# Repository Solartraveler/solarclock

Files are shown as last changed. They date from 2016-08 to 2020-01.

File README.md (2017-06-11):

# solarclock

The aim of this project is to develop an LED alarm clock (DCF77 synchronized),

powered by a solarcell and rechargeable batteries.

A prototype testing for various hardware and a software with most planned
features have been completed.

With Linux, the GUI of the clock can be simulated on PC without building any
hardware. Every menu item can be changed as on the real clock, however there
is no functionality behind the GUI on the PC. Control the simulation with the four
cursor keys.

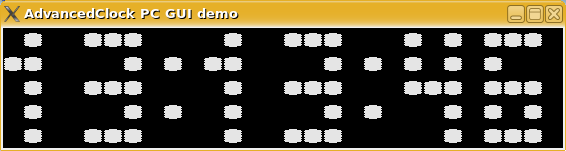
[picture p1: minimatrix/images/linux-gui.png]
Linux GUI simulation


The prototype clock:

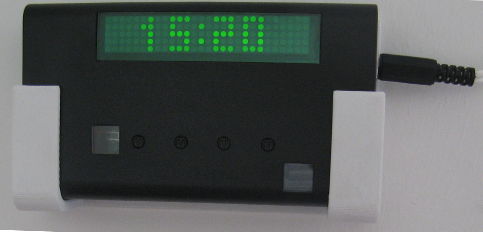
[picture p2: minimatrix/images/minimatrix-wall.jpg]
Real clock


If connected to an external RS232 level converter (19200 baud, no parity,
no extra stop bits, no flowcontrol), and enabled RS232 in the debug
menu, the real clock can be controlled with the w-a-s-d keys over the serial port too.

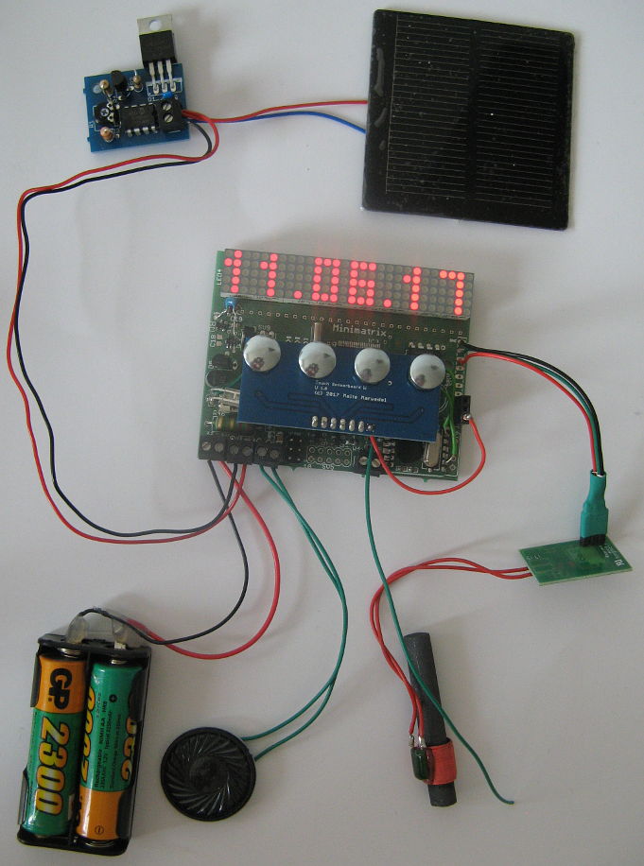
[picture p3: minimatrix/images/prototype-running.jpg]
Version 1.2 without a case


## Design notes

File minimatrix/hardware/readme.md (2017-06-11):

# About the hardware
Version 1.0 is the prototype PCB actually produced.

However it contains a LOT of bugs, so before making your own one, I recommend reading through the bug list and make a new version, starting from the current state of version 1.2.

Please note the new designed ir-sensor board which fits in connector SV2. The ones attached on the v1.0 board simply do not work.

The yellow wires in version 1.1 and 1.2 have been added to the PCB of version 1.0 by wireing on the patchfield.

Genreally, I had two PCBs of version 1.0 produced. The first one is soldered as in schematic version 1.1 and the second one as in schematic 1.2.

Version 1.2 has been improved a bit from version 1.1 and some parts soldered in version 1.1 (but not used there or considered bad) have been removed in version 1.2.

## Userinput

There are two input methods available. Touch and infrared proximity. The software will detect which type is used on startup automatically. Each has its strength and weaknesses. The software could be changed to use classic buttons as third input method with little effort.

## So for the overview of the files:
The brd and sch files are created with Eagle version 5.11 light. The pdf files have been exported from these for easy viewing without the software.

minimatrixV1 brd/sch/pdf: Originally produced PCB, later manually patched to meet the schematics of version 1.1 and 1.2

minimtrixV1-1 brd/sch/pdf: First clock build (the green one). Fixes have been added into the schematic, but not in the board. So you might modify the board before production.

minimtrixV1-2 brd/sch/pdf: Second clock build (the red one). Fixes have been added into the schematic, but not in the board. So you might modify the board before production.

ir-sensorboard brd/sch/pdf: Touchless keys working by infrared reflection sensors. Used on the first clock. Good for use in a kitchen or some other place where you dont want to touch anything. Do not work in bright light, and might get activated by bright flashes by accident. In the daylight they cant be used.

touch-sensorboardW brd/sch/pdf: Use the body capacity as input key. Used on the second clock. Hopefully the ESD protection is sufficient.

solarvoltagelimit brd/sch/pdf: Two schematics and PCBs used for overvoltage and overcurrent protection. The circuit for overcurrent protection is only required for solarcells who can deliver more than 200mA peak. Instead of producing a special PCB, they can be soldered on common perfboard too. Note that the PCBs in these files have never been produced and therefore never tested.

solarclock-touch-voltagelimit brd/pdf: A board from touch-sensorboardW and the voltage limit PCB of solarvoltagelimit combined with predefined breaking points for cheap production as single board.

## License

All my work is published under Attribution-NonCommercial-ShareAlike 4.0 International, however please note that many symbols are work from the authors of the part libraries.

Many symbols are from the Eagle authors.

avr-7.lbr from https://cadsoft.io/resources/libraries/1751/ has been used

And the RFM12 device is from https://www.mikrocontroller.net/topic/90021

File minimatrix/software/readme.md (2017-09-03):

# About the software
The software is divided in two projects. One simple version and one advanced version.

You can edit the menu with my other open source project from

http://menudesigner.sourceforge.net/

## The simple version

Its not containing all planned features of the clock, but is complete enough to run and allow using the clock.
This might be a starting point to get an overview how the code is managed or simply use it if you just dont want a heavily featured clock.
About 29KiB of the flash is used.

### Features:

- DCF77 synchronization

- Showing Date and Time

- Debug print and debug control over RS232

- Adjust brightness according to surrounding brightness

- Charge the batteries

- Set an alarm to a given time -> beep - beep - beep

- Set a counter to give alarm in a given number of minutes.

- Lets the user control with the four keys

- Shows the temperature

- Warns about low battery

- Keylock preventing accidental key presses

- Set RFM12 module to power down mode

- Suppors the infrared (reflex light barrier) keys.

- Many many settings:

  * Brightness manual/automated

  * Show seconds/hide seconds

  * Manual charger control (on/off/automatic)

  * Set mAh of battery

  * Set calibrated value for charge measurement

  * Set level for accepted DCF77 error

  * Set refreshrate

  * Set volume of beep

  * Set frequency of beep

  * Set current consumption for used LEDs

  * Set time until alarm a beeping alarm goes silent without user interaction

  * Select which type debug messages should be printed on the RS232 interface

  * Selects if clock should switch display completely off when dark or stay always at at least minimal brightness

- Showing many informations:

  * Current voltage

  * Current charging current

  * Current charged state of battery

  * Consumend mAh since power on

  * Quality of DCF77 signal

  * Raw value of one key

  * Raw value of lightning sensor

  * Show RC oscillator and CPU usage (percentage of time they are not stopped)

  * And shows even more with RS232 connected

### Known bugs:

- Input keys could be improved, but real bugs - none.

## The advanced version

The advanced version contains all features of the simple version and uses about 50KiB flash.

Unlike the simple clock version, the advanced version contains source code from third parties:

The RC-5 decoder software is from Peter Dannegger.

The two wire interface library is from Atmel Corporation.

The project for the other compatible RFM12 communication endpoint (based on an ATmega8) can be found there: https://www.mikrocontroller.net/topic/71682#4902303

### Completed features

- Event logger in external I2C EEPROM (reboots and cause of it, temperature, chargings, DCF77 sync times and time delta ...)

  * Supports eeproms with one I2C address, two bytes for addressing and at least 16 byte page size.
   This is usually the case for all 8KiB - 64KiB eeproms. Each log entry requires 23 bytes.
   Storing is done FIFO based without explicit index storing, so eeprom life is maximized.
   Size detection is done automatically on first startup.

- RC5 remote control receiver

- Second alarm with repeating, non repeating, only some days of the week, settings

- Power down on certain times of the day, saving power

- Wireless control and read of logger with RFM12

- Manually setting time and date in the case there is no DCF sync

- Test pattern for the LED matrix

- Pin test for checking proper soldering

- Supports both infrared or capacitive keys - does autodetect on startup.

- Calibration of the internal crystal in the range of +- 0.036%

- Heap to stack closest gap (=free RAM) reporting. (77% of the 4KiB are used)

### Planned features

- Its finished :)

### Known bugs:

- Input keys could be improved

- There should be only one clock with an RFM12 active within the RX/TX range - Otherwise both try to act packages from a third station and communication becomes unstable

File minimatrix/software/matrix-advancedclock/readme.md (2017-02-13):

This is the software containing everything you need to have a working alarm clock.
It uses all hardware on the PCB version 1.1 and has many special features therefore "advanced".
Files which are equal to the ones in the simple version are just symlinks. This makes maintaining two versions more easy.

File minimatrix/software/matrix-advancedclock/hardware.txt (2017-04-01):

Hardware:  Interrupt priority:  Prescaler: Modified on speed boost:  Usage:
RTC clock: compare-high         1          no                        used for display
RTC clock: overflow-low         1          no                        used for clock
timer C0:  overflow-low         1          yes                       used for sound                (needs interrupt as long as sound is active)
timer C1:  --                   256        no                        used for performance counter
timer D0:  overflow-medium      1          yes                       used for dcf77 sampling       (needs interrupt as long as signal is syncronizing)
timer D1:  --                   8          yes                       2MHz rc clock synchronization
timer E0:  overflow-low         1          no                        used for RC-5 decoding        (needs interrupt only if incoming signal is detected)
timer E1:  overflow-low         1          yes                       used for RFM12 decoding       (needs interrupt as long as module is active)
USART E0:  tx-medium                       yes                       used for RS232 print           medium level permits debug print in low level interrupts
timer F0:  --                   1          no                        used for touch keys

Possible timer prescalers: 1, 8, 64, 256, 1024
For analyzing the DCF signal, the CPU speed is boosted from 2MHz to 16MHz,
this requires a change of the running timers to preventing running faster.
Therefore the prescalers are changed from 1 to 8 and from 8 to 64 for timers
where this matters.

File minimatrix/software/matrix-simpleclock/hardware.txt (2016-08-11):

RTC clock: Used for display + rtc
timer C0: used for sound
timer C1: used for performance counter
timer D0: used for dcf77 sampling
timer D1: 2MHz rc clock synchronization

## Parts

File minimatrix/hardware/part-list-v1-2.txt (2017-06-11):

This is the part list for schematic version 1.2.
It is build on the patched PCB of version 1.0
PCB1 is the main PCB with the matrix and ATxmega.
PCB2 is the required extra PCB for the voltage limitation of the solar cell.
PCB3 is the touch keys PCB.

Number  Description              Part of:                                   Supplier     Order-number      approx price for 1x in Euro
 1x     24AA512P 32KB EEPROM     IC1                                        Reichelt     24AA512-I/P       1.85
 1x     Opamp MCP6051            IC2                                        Reichelt     MCP 6051T-E/OT    0.69
 1x     ATxmega 100QFP 64KB      IC3                                        Reichelt     ATXMEGA 64A1-AU   4.95
 1x     RFM12                    U$2                                        Pollin       810 049           4.95
 1x     MCP6042P                 PCB2:IC2A                                  Reichelt     MCP 6042-I/P      0.93
 1x     LPT80A Phototransistor   T1                                         Reichelt     LPT 80            0.70
 1x     Temperature Sensor       R1                                         Reichelt     KTY 81-221        0.57
 1x     47k 0805                 R2                                         Reichelt     SMD-0805 47,0K    0.03
 2x     220 0805                 R3, R4                                     Reichelt     SMD-0805 220      0.03
 6x     1000k 0805               R5, R38, PCB3:R13-R16                      Reichelt     SMD-0805 1,00M    0.03
28x     Resistors for LEDs 27Ohm R6-R33                                     Reichelt     SMD-0805 27,0     0.015
 1x     33k 0805                 R34                                        Reichelt     SMD-0805 33,0K    0.03
 1x     Potentionmeter 100k      R35                                        Reichelt     PT 6-S 100K       0.24
 1x     110k 0805                R36                                        Reichelt     SPR-0805 110K     0.24
 3x     220k 0805                R37, R40, R41                              Reichelt     SMD-0805 220K     0.03
 2x     360k 0805                R42, R43                                   Reichelt     RND 0805 1 360K   0.02
 2x     100k 0805                R44, R45                                   Reichelt     SMD-0805 100K     0.03
 1x     2,2Ohm resistor          R46                                        Reichelt     2W METALL 2,2     0.13
 4x     100k 1206                PCB3:R9-R12                                Reichelt     RND 1206 1 100K   0.02
 1x     47k                      Patchfield                                 Reichelt     1/4W 47K          0.103
 1x     1k                       Patchfield                                 Reichelt     1/4W 1,0K         0.103
 1x     Poti 100k                PCB2:R1                                    Reichelt     PT 6-L 100K       0.27
 1x     100k                     PCB2:R2                                    Reichelt     1/4W 100K         0.103
 1x     240k                     PCB2:R3                                    Reichelt     1/4W 240K         0.103
16x     Condensators 100nF 0805  C2, C3, C6-C9, C12-C17, C19, PCB3: C9-C11  Reichelt     X7R-G0805 100N    0.05
 2x     100µF 1206               C20, C21                                   Reichelt     X5R-G1206 100/6   0.34
 1x     47µF 1206                C22                                        Reichelt     X5R-G1206 47/6    0.20
 2x     100nF                    Patch between R35 and R36, PCB2:C1         Reichelt     X7R-2,5 100N      0.05
 4x     1nF 3000V                PCB3:C1-C4                                 Reichelt     X7R 1812 CN 1,0N  0.16
 4x     10nF 200V                PCB3:C5-C8                                 Reichelt     X7R 0805 CH 10N   0.04
 1x     1N5817-B                 D4                                         Reichelt     1N 5817           0.06
 2x     Z-Diode LM385Z-1.2       D5, PCB2:D1                                Reichelt     LM 385-Z1,2       0.39
 8x     SM6T36A                  PCB3:D1-D8                                 Reichelt     P6SMB 36A SMD     0.17
 4x     7x5 red   TA07-11SURKWA  LED1-LED4                                  RS           719-2572          2.31
 8x     IRLML6402PbF P-Mosfet    Q3-Q10                                     Reichelt     IRLML 6402        0.15
 2x     BSS138       N-Mosfet    Q11, Q12                                   Reichelt     BSS 138 SMD       0.04
 1x     IRLZ34N                  PCB2:Q1                                    Reichelt     IRLZ 34N          0.45
 1x     Oscillator 32kHz         Q2                                         Reichelt     0,032768          0.12
 1x     Fuse with Socket 250mA   U$3                                        Reichelt     SMD-HASF 0,25A    1.10
 1x     Pin header 2x3           SV1                                        Reichelt     MPE 087-2-006     0.14
 1x     Plug connector 6pin      SV2                                        Reichelt     MPE 094-1-006     0.21
 2x     Plug connector 3pin      SV4, and with wire on SV4                  Reichelt     MPE 094-1-003     0.13
 1x     Pin header 1x6           split: PCB3: SV1, with wire on PCB3:Pad1   Reichelt     MPE 087-1-007     0.16
 5x     Screwed connection       J1 - J4, PCB2:J1                           Reichelt     AKL 059-02        0.24
 1x     NIMH AA 2er pack                                                    Reichelt     ENELOOP 2XAA      5.40
 1x     Battery holder           connect to J2                              Reichelt     HALTER 2XAAZ      0.35
 1x     Speaker                  connect to J3                              Reichelt     BL 28             1.50
 1x     DCF77 receiver           connect to SV4                             ELV          68-09 16 10       9.95
 1x     Solarcell 200mA-250mA 4V connect to J1                              Ebay                          ~9.00
 1x     PCB production           PCB1                                       Platinensammler.de            31.72
 1x     PCB production           PCB2, PCB3                                 electrow.com                 ~10.00
                                                                                                   Sum: ~103.78€
 1x     Some wire/strand for Solar cell, batteries, speaker and DCF77 connector
 1x     Some case
 1x     Some glass or acrylic glass for the solar cell
 1x     Some transparent-red acrylic glass for the display
 4x     Small metal plates as touch buttons (for example use 4mm screws)
 1x     Some PB-free tin-solder
 1x     Some heat shrink tube
 1x     Some hot glue
 6x     Shipping for Reichelt, Pollin, RS, ELV, Platinensammler or electrow.com, acrylic glass           ~5.00

Possible changes in options from the list above:
A: Remove RFM12
   U$2 and C3 100nF not needed
B: Remove Logger
   IC1 and C6 100nF not needed
C: Remove Beeper
   C22, Q10, Q12, R41, J1, Speaker not needed
D: Reduce batteries from AA to AAA and select other battery holder.
   Make sure allowed charging current is higher or equal the maximum current of the solar cell.
E: Increase or decrease solar cell. If increasing to > 250mA, add a current limiting polyfuse.
   to make sure the batteries are not fast overcharged in the case of software/hardware failure.
F: Instead of the red matrix LEDs (LED1-LED4), orange or green parts can be used:
   orange: TA07-11SEKWA
   green:  TA07-11CGKWA
G: An IR receiver can be added:
   Add 1x 100nF 0805 (C1) and 1x TSOP 31238 (IR1)
H: The wires can be directly soldered to the PCB, remove all "Screwed connection" J1-J4, PCB2:J1
I: Instead of the touch buttons, the IR buttons (ir-sensorboard PCB) can be used:
   Remove all parts for PCB3, Add PCB4.
   Add 1x IRML6402, 4x 39 0805, 4x 47k 0805, 4x SG2BC
J: The LEDs and the EEprom can be placed in a socket (testing different colors etc)
   Add 4x Socket DIL 14, 1x Socket DIL 8
   Placing the LEDs into a socket is recommend as it helps equaling the height of them to the touch buttons.

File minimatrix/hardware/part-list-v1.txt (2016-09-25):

BE CAREFUL, this list is for parts of PCB vesion 1.0. Some parts not have been replaced on version 1.1 (old parts are on this list, new ones not).

Bauteilhöhe Poti: 7,7mm
LED + Sockel Höhe: Sockel=4,1mm  LED= 6,4mm -> 10,5

PCB Dimension:
75x60x(10,5+1.5+3)=75x60x15
Akku Dimension: 58x32x(13,5+2mm) = 15,5mm
-> Höhe = 31mm

Optionen: Jeweils entweder A, B oder C bestellen

Selber gewählt: 1A, 2B, 3B, 4A, 5B

Bauteile                  Reichelt Bestellnummer   €
1x ATxmega 100QFP 64KB    ATXMEGA 64A1-AU   4,95 Option 4A
1x ATxmega 100QFP 128KB   ATXMEGA 128A1-AU  6,60 Option 4B
1x IR 38KHz TSOP31238     TSOP 31238        0,77 Option 3A
1x IR 36kHz TSOP31236     TSOP 31236        0,77 Option 3B
1x 24FC64P  8KB EEROM     24FC64-I/P        0,54 Option 5A
1x 24AA256P 32KB EEPROM   24AA256-I/P       1,05 Option 5B
1x 24AA1025 128KB EEPROM  24AA1025-I/P      3,50 Option 5C (software only supports up to 64KB right now)
1x LHI878 PIR Sensor      LHI 878 RF        2,70
1x LPT80A Fototransistor  LPT 80            0,70
1x Temp Sensor 2k         KTY 81-221        0,57
1x Poti 100k CA6H         PT 6-S 100K       0,24
1x MCP6051                MCP 6051T-E/OT    0,69
1x LM385Z-1.2             LM 385-Z1,2       0,39  Option 1A
1x LT1004C-1.2            LT 1004 CZ-1,2    1,95  Option 1B (spart 15µA)
15x 100nF 0805            X7R-G0805 100N    0,05
8x IRLML6402PbF           IRLML 6402        0,15
                                          ZwSumme=14,01
2x BSS138                 BSS 138 SMD       0,04
3x 100µF 1206             X5R-G1206 100/6   0,34 Option 6A (ausverkauft)
3x 47µF 1206              X5R-G1206 47/6    0,20 Optoin 6B
12x 22pF 0805             NPO-G0805 22P     0,05
1x 1 15mm                 2W METALL 1,0     0,11
20x 27 0805               SMD-0805 27,0     0,082
2x 220 0805               SMD-0805 220      0,103
2x 4.7k 0805              SMD-0805 4,70K    0,103
1x 47k 0805               SMD-0805 47,0K    0,103
1x 68k 0805               SMD-0805 68,0K    0,103 Option 1A
1x 33k 0805               SMD-0805 33,0K    0,103 Option 1B
2x 100k 0805              SMD-0805 100K     0,103
                                          ZwSumme=4,411
1x 110k 0805              SPR-0805 110K     0,24
1x 200k 0805              SPR-0805 220K     0,24
3x 220k 0805              SMD-0805 220K     0,103
1x 1000k 0805             SMD-0805 1,00M    0,103
24x 10000k 0805           SMD-0805 10,0M    0,082
1x Spule 10µH             L-MICC 10µ        0,15
1x 1N5817-B               1N 5817           0,06
1x Quarz 32kHz            0,032768          0,12
1x Quarz 4MHz             4,0000-HC49U-S    0,19
1x Sicherung 250mA        SMD-HASF 0,25A    1,10
1x Stiftleiste 2x5        MPE 087-2-010     0,25
1x Stiftleiste 1x3        MPE 087-1-003     0,08 Option 2A
                                          ZwSumme=4,81
1x Stiftleiste 2x3        MPE 087-2-008     0,20
2x Stiftleiste 1x2        MPE 087-1-002     0,05 Option 2A
2x Stiftleiste 1x6        MPE 087-1-006     0,15 Option 2A
1x Stiftleiste 1x40       SL 1X40G 2,54     0,18 Option 2B

1x Buchsenleiste 1x10     BL 1X10G8 2,54    0,18
1x Buchsenleiste 1x6      MPE 094-1-006     0,25
4x Schraubanschluss 1x2   AKL 059-02        0,24
4x Sockel DIL 14          GS 14             0,04
1x Sockel DIL 8           GS 8              0,04
1x Fresnel Linse          FRESNEL-0650      1,80
2x Akkus NIMH AA          ENELOOP 4XAA      10,50 /[4Stück]
1x Akkuhalter             HALTER 2XAAZ      0,35
1x Lautsprecher           BL 28             1,50
                                          ZwSumme=11,09
1x Gehäuse
1x Solarzelle 3V          -------  ca 3,3V Leerlauf , 360mA max.      ~20,00
1x PCB Herstellung        -------  mikrocontroller.net Platinensammler 31,72
1x RFM12                  -------  Pollin    810 049                    4,95
4x LED Matrix Module      -------  RS        TA07-11CGKWA               2,77

Total: 93,76

IR Sensor board:
1x IRML6402                                            Q1
4x 39 0805                                  0,103      R1, R2, R3, R4
4x 47k 0805                                 0,103      R5, R6, R7, R8

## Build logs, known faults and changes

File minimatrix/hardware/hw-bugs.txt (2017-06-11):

Version 1.0 of the board contains the following bugs:
The changes are documented in version 1.1 and 1.2, however no such new PCB has been produced.

1. TWI
   Problem: TWI misses the ~2k pull up resistors on both signals.
   Workaround: Use TWI with internal 20k pull-up resistors. This will only work on very low clock frequencies.
2. Light sensor
   To measure the full dynamic of the surrounding, different values for R2 are needed.
   Workaround: Use R2 = 1MOhm, and connect PE4 with 100kOhm and PE7 with 4.7kOhm to the photo transistor.
   Note: Due connection of R2 with R5, measurements with PE4 or PE7 as high, must remove the effects of T1 by measuring T1 and do some math.
3. JTAG
   The connector is too close to J4.
   Workaround: Use PDI for programming or do not equip J4.
   Note: JTAG has never been tested.
4. Jumpers J1, J2, J3, J4
   4.1 The jumpers are lager than expected. Text in front can't be read. Workaround: None
   4.2 D4 has too less space. Workaround: Solder D4 from the bottom
5. LED Voltage regulator
   5.1 Disconnecting the power supply by opening SV9, results in VCC as VCCLED. TOO HIGH VOLTAGE! Workaround: Never open SV9 unless all matrix LEDs are off. Only open tesing purpose (eg measuring current consumptions).
   5.2 C18 makes regulation bad. Workaround: Don't equip C18.
   5.3 Regulation swings. Workaround: Connect 100nF from VCCLED to the positive input of IC2.
   5.4 Regulation swings. C20 is too small. Use at least 150µF. Connect an additional electrolyte in parallel.
   5.5 The planned 30Ohm as resistor for the LEDs cant be bought easily. Workaround: Use 27Ohm.
6. Touch
   Do not equip C23 ... C30.
   Sensitivity too low. Make PCB sensing field larger. Or better use IR distance sensors (other .brd file)
7. Level converter for PDI bad.
   Workaround: Do not equip SV8, D1, D2. Lower R3, R4 to 200Ohm. Use 3.3V programmer.
8. Too high power consumption
   Do not equip D3.
9. Screw holes
   The screw holes are too close to some pads.
   Workaround: Do not use or use isolated screws.
10. Crystals
   10.1 There are vias below Q1 ans Q2 which may result in a short circuit if the crystal touches these.
        Workaround: Solder pins of Q1 with some distance to the PCB. Add some isolating tape below Q2.
   10.2 C10 and C11 are not needed. Do not equip.
11. SV4
   The holes only allow soldering female header and are too small for male header.
   Workaround: Use female header.
12. RFM12:
  12.1 There are vias below the RFM12 module wich might result in short circuit
   Workaround: Put a piece of paper between pcb and RFM12 while soldering, remove later -> results in some space between PCBs
  12.2 RFM12 needs external reset for proper operation
   Woraround: Connect pin PE5 from PIR detector to reset (do not use PIR detector)
13. PIR Detector does not work
   Workaround: Do not solder PIR detector and R39
14. R42 and R43 are too low, resulting in a maximum voltage measurement range of 3.2V -> not enough for charger
   Workaround: Solder 360kOhm for both resistors
15. Charging current cant be measured very well
  Use 2.2Ohm for R46.

==ir-sensor==
16. The ir-sensor board uses SG2-BC photointerrupters as contact-free keys. However direct sunlight results in accidential key presses and intentional key presses become impossible.
   Workaround: Only use clock in the shadow from the sun or with artifical light.
==touch-sensor==
17. The Diodes D1-D8 in the PCB are difficult to solder when C1-C4 are already soldered.
   Workaround: Solder D1-D8 before soldering C1-C4.
==Voltage limit==
18. The 75k potentiometer is difficult to buy.
   Workaround: Use 100k

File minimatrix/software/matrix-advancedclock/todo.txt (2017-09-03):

Advanced clock TODO:
Display flicker                     -> Done, needs longtime testing. Needs to check if problem is solved even without enabled workaround in debug menu (increases the power consumtion a little)
Power save mode selectable          -> Done
Power save mode for specific times  -> Done
RC-5 Receiver                       -> Done
RFM12 RX/TX                         -> Done
Advanced timer                      -> Done
Pin Selftest                        -> Done
Logger                              -> Done
Reboot/runtime counter              -> Done
Redundant config load/store         -> Done
Crashes on keypress                 -> Done
Touch keys                          -> Done
Smooth brightness adjust            -> Done (source of flicker while brightness reduce is likely caused by insufficient LED voltage regulation)
Summer winter time adjust           -> Done
DCF77 sync wait time adjustable     -> Done
Logger status write time adjustable -> Done
Manual time adjust                  -> Done
Manual charger state adjust         -> Done
Auto powersave on critical voltage  -> Done
Calibration option for crystal      -> Done
Test Patterns                       -> Done
IR Keys                             -> Done

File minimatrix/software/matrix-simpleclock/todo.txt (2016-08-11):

Charger working -> ok
Better DCF77    -> ok
Better Keys     -> ok
Power estimator -> ok
Display flicker -> still no idea

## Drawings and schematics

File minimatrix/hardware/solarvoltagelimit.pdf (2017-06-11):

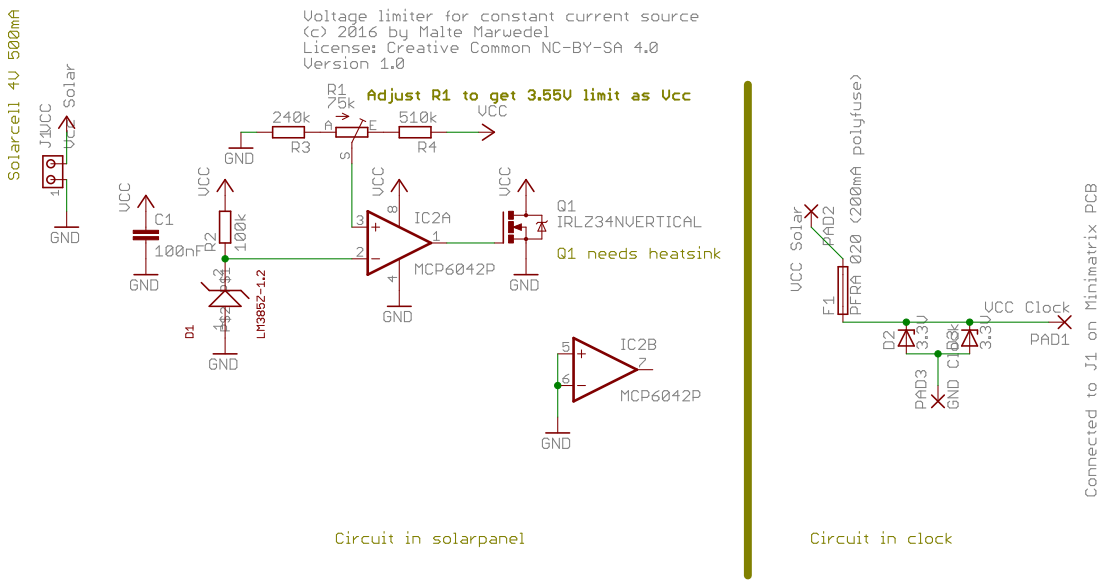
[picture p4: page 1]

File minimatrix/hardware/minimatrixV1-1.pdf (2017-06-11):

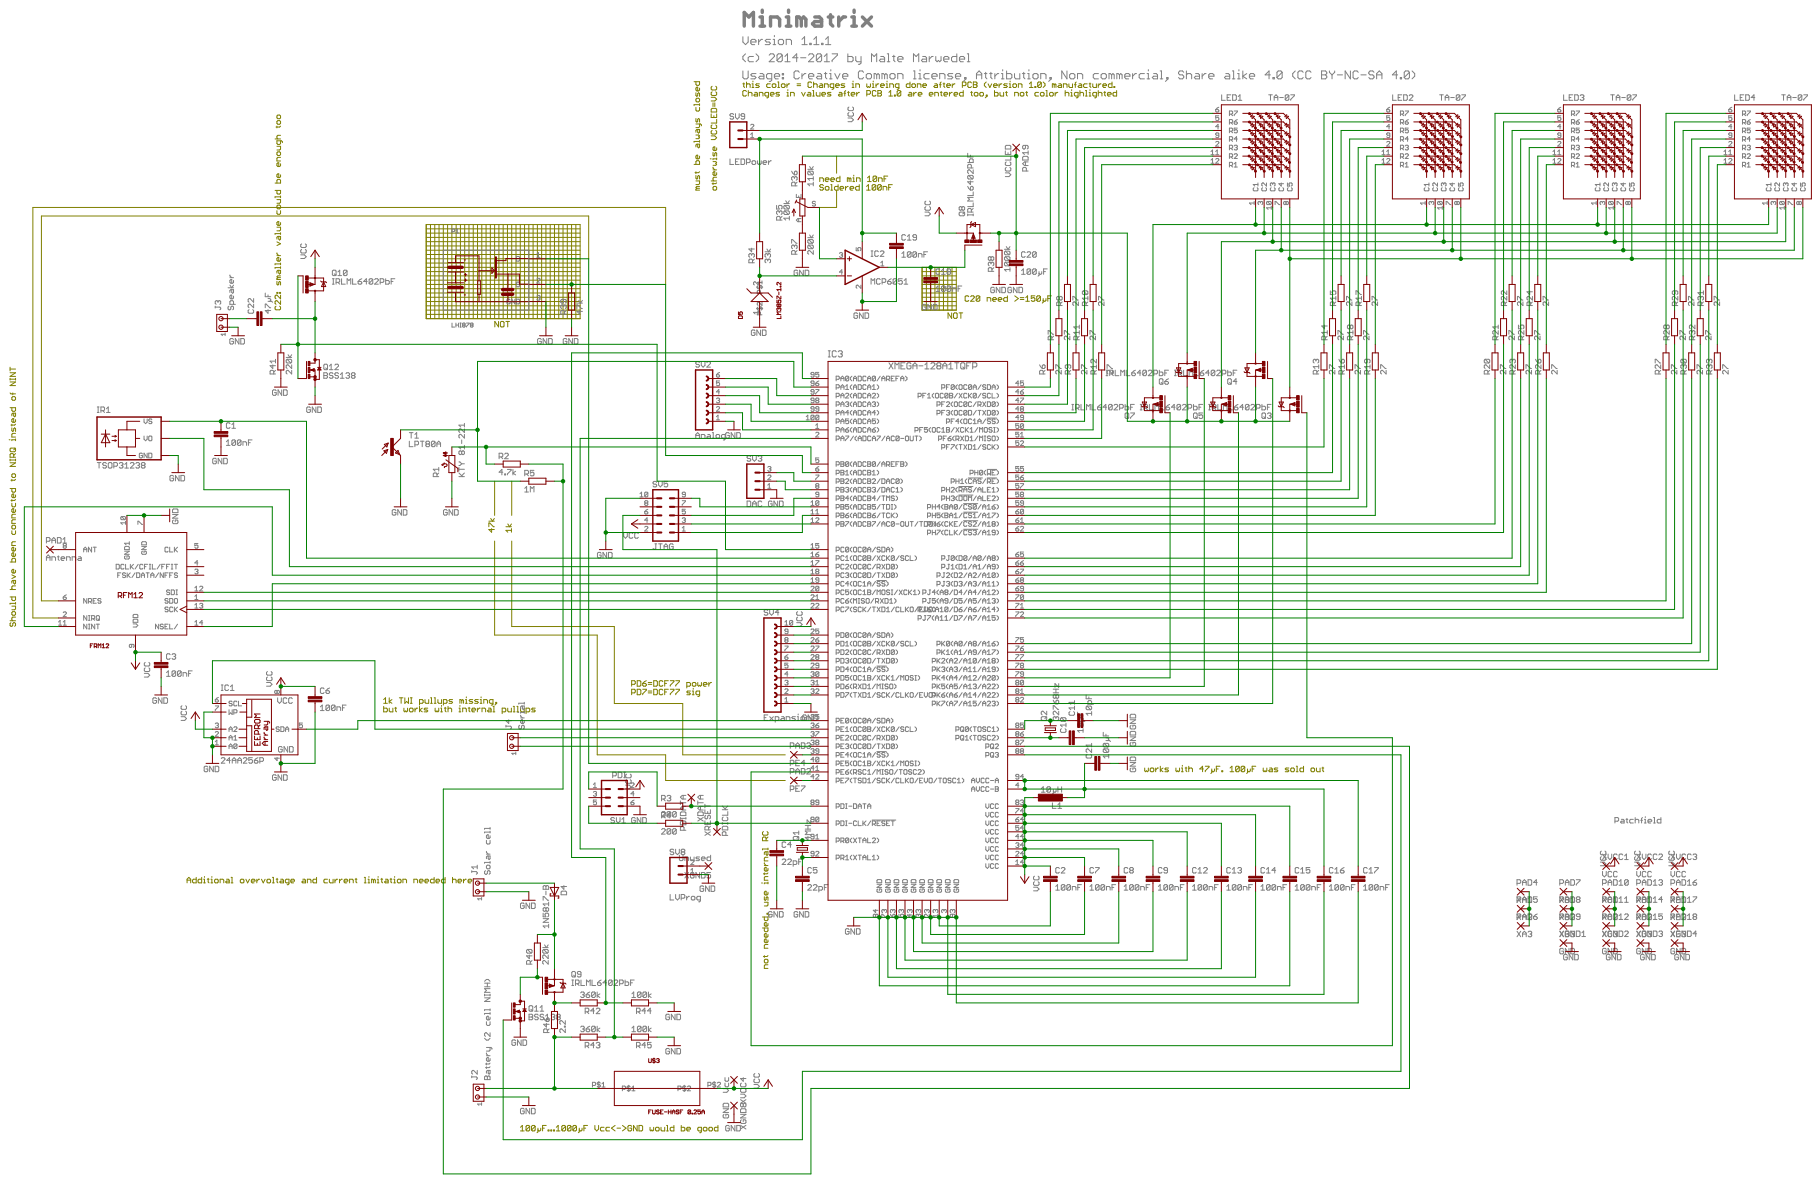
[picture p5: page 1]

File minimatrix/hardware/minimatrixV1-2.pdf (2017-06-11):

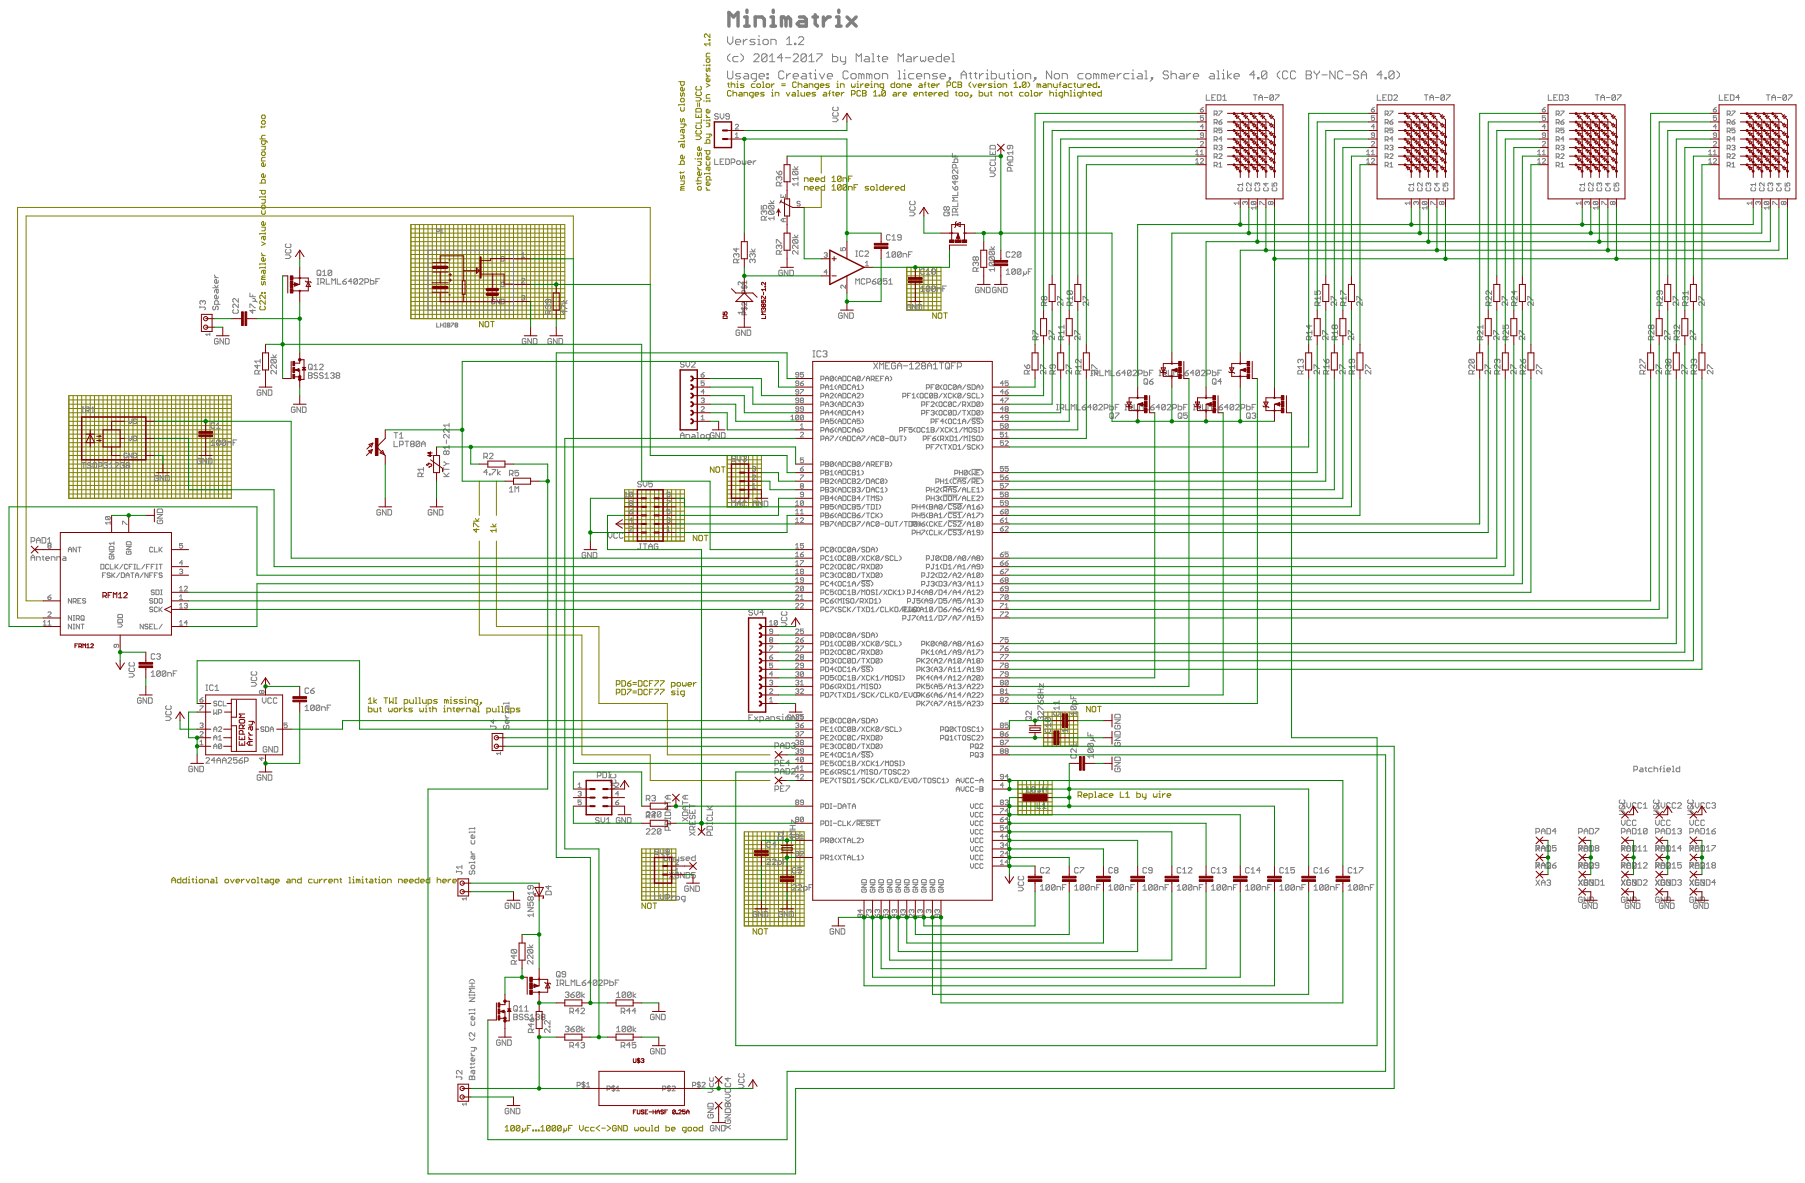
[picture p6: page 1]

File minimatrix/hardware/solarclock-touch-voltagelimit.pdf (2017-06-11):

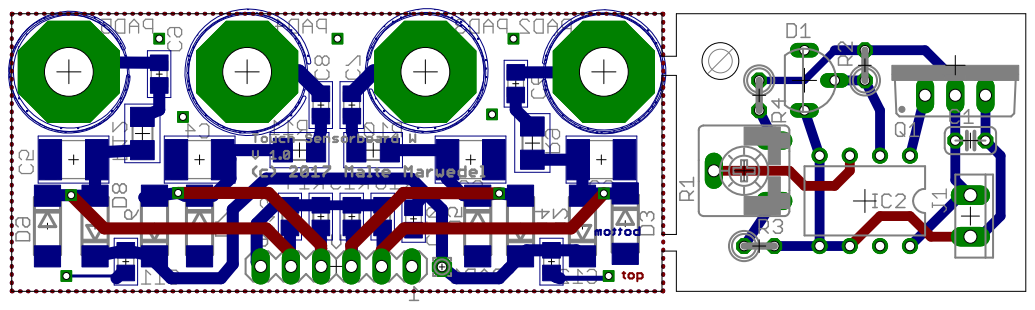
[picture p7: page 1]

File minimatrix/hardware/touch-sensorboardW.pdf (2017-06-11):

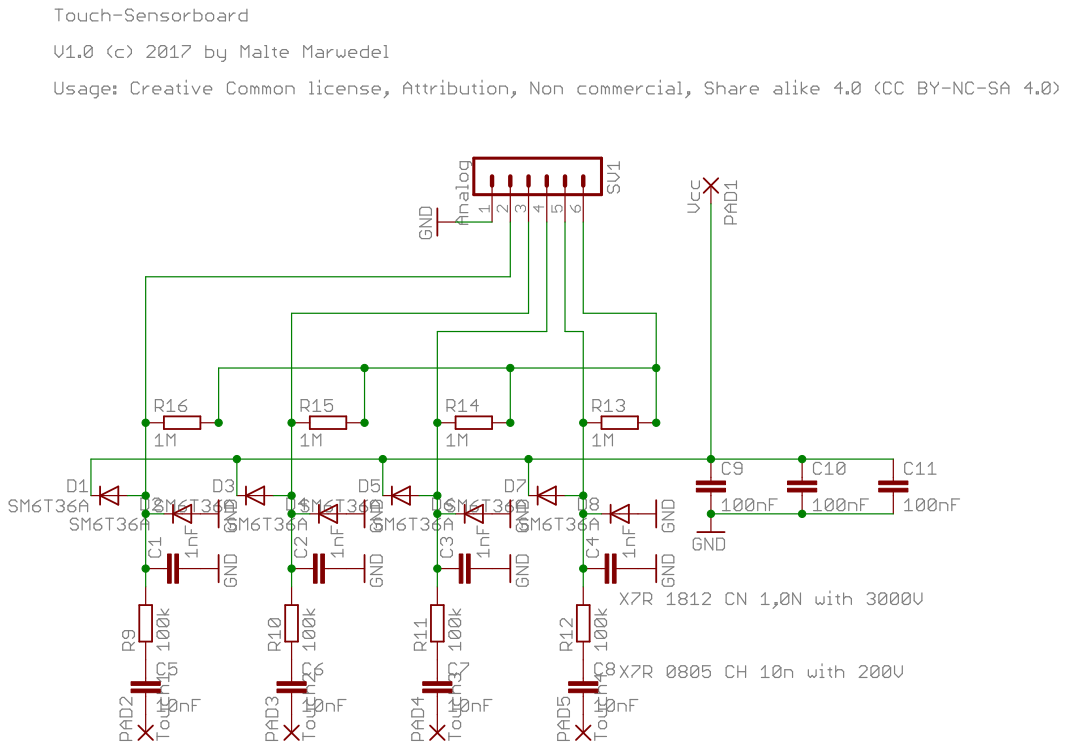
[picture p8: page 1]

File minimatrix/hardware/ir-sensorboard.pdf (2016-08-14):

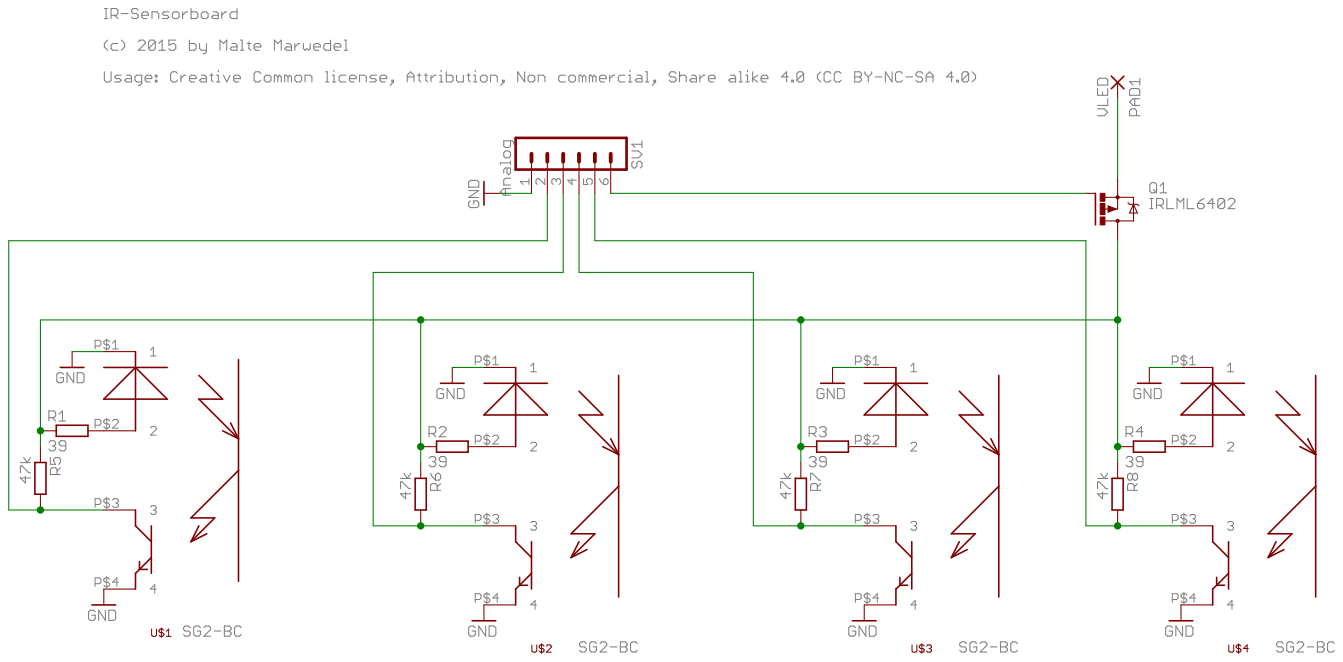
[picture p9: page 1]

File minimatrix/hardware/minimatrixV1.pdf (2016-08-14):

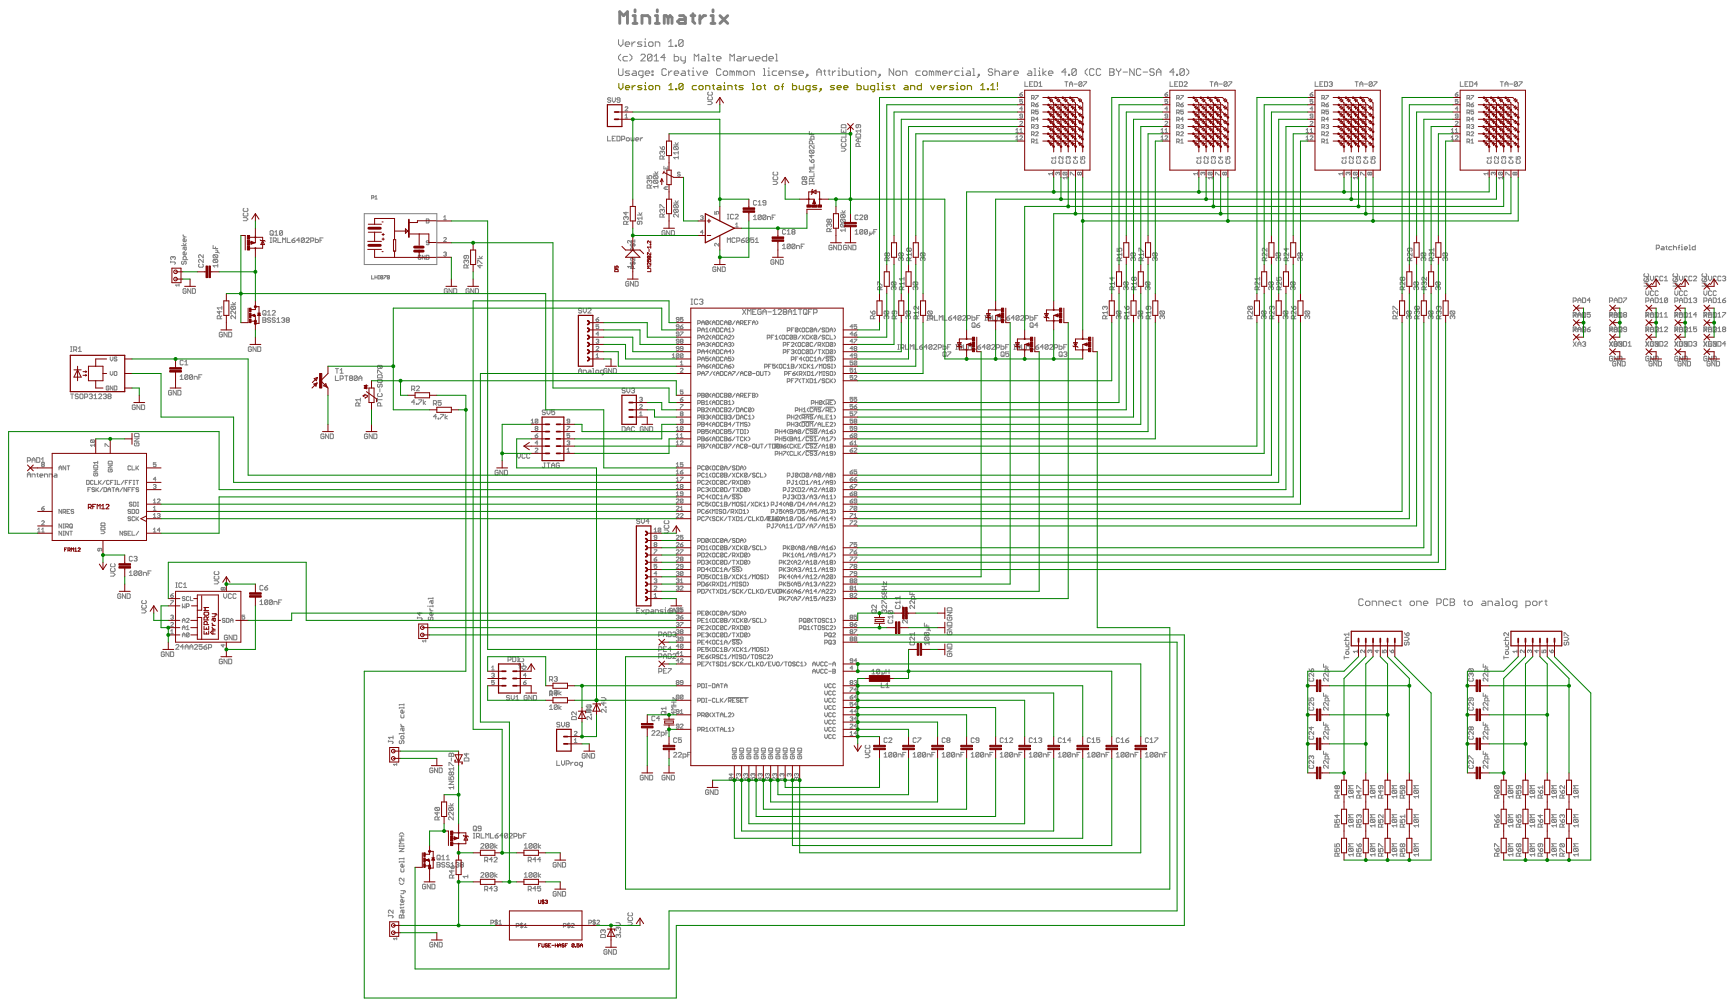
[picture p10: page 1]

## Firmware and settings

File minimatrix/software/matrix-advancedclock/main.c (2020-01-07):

/* Matrix-Advancedclock
  (c) 2014-2018 by Malte Marwedel
  www.marwedels.de/malte

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
    You should have received a copy of the GNU General Public License
    along with this program; if not, write to the Free Software
    Foundation, Inc., 59 Temple Place, Suite 330, Boston, MA  02111-1307  USA
*/

#include <util/delay_basic.h>
#include <avr/pgmspace.h>
#include <avr/interrupt.h>
#include <avr/sleep.h>
#include <avr/wdt.h>
#include <avr/io.h>
#include <avr/eeprom.h>
#include <stdio.h>
#include <string.h>
#include <ctype.h>

#include "main.h"
//needs F_CPU from main.h:
#include <util/delay.h>
#include "menu-interpreter.h"

#include "displayRtc.h"
#include "rs232.h"
#include "sound.h"
#include "dcf77.h"
#include "clocks.h"
#include "rfm12.h"
#include "adc.h"
#include "gui.h"
#include "config.h"
#include "charger.h"
#include "timeconvert.h"
#include "rc5decoder.h"
#include "logger.h"
#include "debug.h"
#include "touch.h"
#include "finecalib.h"
#include "stack.h"


settings_t g_settings; //permanent settings
sysstate_t g_state; //floating state of main program
uint8_t g_debug __attribute__ ((section (".noinit")));
uint8_t g_debugint __attribute__ ((section (".noinit")));

void waitms(uint16_t ms) {
	while (ms) {
		_delay_loop_2(F_CPU/4000); //4 cycle per loop 4MHz -> 1ms: 1000 loops
		ms--;
	}
}

void power_setup(void) {
	PR_PRGEN = 0x1F;
	PR_PRPA = 0x7;
	PR_PRPB = 0x7;
	PR_PRPC = 0x7F;
	PR_PRPD = 0x7F;
	PR_PRPE = 0x7F;
	PR_PRPF = 0x7F;
	/*flash power reduciton hw bug:
	 can not be used together with power save or extended standby */
	//NVM_CTRLB |= NVM_FPRM_bm | NVM_EPRM_bm;
	NVM_CTRLB |= NVM_EPRM_bm;
	CCP = 0xD8;
	MCU_MCUCR = 1; //disable jtag, saves power
}

void pull_port(PORT_t * port, uint8_t bitmask) {
	uint8_t i;
	for (i = 0; i < 8; i++) {
		register8_t * pinctrl = (&(port->PIN0CTRL)) + i;
		if (bitmask & 1) {
			*pinctrl = PORT_OPC_PULLUP_gc;
		} else {
			*pinctrl = PORT_OPC_PULLDOWN_gc;
		}
		bitmask >>= 1;
	}
}

static void pull_all_pins(void) {
	pull_port(&PORTA, 0x4);
	pull_port(&PORTB, 0x0);
	pull_port(&PORTC, 0x1);
	pull_port(&PORTD, 0xFF);
	pull_port(&PORTE, 0x4F);
	pull_port(&PORTF, 0xFF);
	pull_port(&PORTH, 0xFF);
	pull_port(&PORTJ, 0xFF);
	pull_port(&PORTK, 0xFF);
	pull_port(&PORTQ, 0x03);
	pull_port(&PORTR, 0x03);
}

void flash_status_led(uint8_t status) {
	PORTK.OUTCLR = (1<<4); //enable one matrix line
	PORTF.OUT = ~status; //0 = on, 1 = 0ff
	_delay_loop_2(F_CPU/200);
	PORTF.OUT = 0xFF;
	PORTK.OUTSET = (1<<4); //disable one matrix line
}

void reboot(void) {
	config_save();
	disp_configure_set(0, g_settings.displayRefresh);
	while (eeprom_is_ready() == 0); //wait for config to finish
	cli();
	CCP = 0xD8; //change protection register
	RST.CTRL = 1; //software reset
	while(1); //if we fail before, the watchdog will do it
}

/*Estimates the current µA every second. This is a pure mathematical
  estimation, without any real current measurements.
  Basically, the main consumers are the MCU and the LEDs, so everything else
  will be handled as simple constant consumption offset.
  Note that the value will only be updated once per second, while the brightness
  is updated twice, this error can be accepted.
  16.98mA total consumption at max brightness and 63 dots on (RS232 debug on)
  ~2.75mA total consumtion at 1 brightness and 32 dots on (RS232 debug on)
  ~2.75mA with out LEDs inserted or brighntess 0 (RS232 debug on)
	~2.2mA with leds of brightness 0, RS232 debug off
  LED consumption one dot max brightness: 225µA

*/
static void update_consumption(void) {
	uint64_t consumptionOld = g_state.consumption;
	/*Consumption by the LEDs depending on the brightness and number of LEDs
		first multiplication fits in 16 bits: 140 max dots * 255 max brightness
		Note: the consumption is underestimated if RFM12 is active. Reason:
		Brighness is boosted to avoid delays in interrupts - see displayRtc.c.
		The value is however small compared to the other usage of the RFM12 and
		therefore ignored here.
	*/
	uint32_t uas = (uint16_t)g_state.dotsOn * (uint16_t)g_state.brightness;
	uas *= (uint32_t)g_settings.consumptionLedOneMax;
	uas /= 255;
	/*
	  constant offset values
	  Vcc measurement: 16µA
	  Poti:            5µA
	  LM358-1.2:       31µA
	  MCP 6051:        29µA
	  Sum:             81µA
	  DCF77 module:    70µA
	  ATXMEGA standby: <1µA
	  Oscilloscope sampling for 1..2 seconds: brighntess = 1,
	  no RS232 and no DCF77: 847µA -> assume 840µA without LEDs

	  According to data sheet:
	  Active supply 2.4V @ 2MHz: ~1100µA
	  Idle supply 2.4V @ 2MHz:    ~340µA
	  2MHz RC supply:             ~120µA
	  Each timer:                  ~18µA
	  RS232:                      ~7.5µA -> so little, ignore

	usually there is 8% cpu load -> 88µA
	and there is 12% rc load ->     14µA
	and 4% idle load ->             13µA
	                           sum: 115µA
	so the constant offset for consumption is approx: 840 - 115 -> 725µA

	*/
	if (dcf77_is_enabled()) {
		uas += 88; //timer ~18µA + receiver ~70µA
	}
	uas += (uint16_t)g_state.performanceRcRunning * 120 / 256; //120 / 256;
	uas += (uint16_t)g_state.performanceCpuRunning * 1100 / 256; //1100 / 256;
	uas += (uint16_t)(g_state.performanceRcRunning - g_state.performanceCpuRunning) * 340 / 256; //340 / 256;
	uas += 674; //constant offset (after R39 removal, otherwise + 51µA)
	if (g_state.rc5modeis) {
		uas += 350; //typical current according to datasheet at 3.3V.
	}
	if (g_state.rfm12modeis) {
		uas += 11000; //typical current according to datasheet at 2.7V (rx mode 433MHz)
	}
	g_state.consumption += uas; //64 bit addition
	if (g_settings.debugRs232 == 0xA) {
		//the sprintf implementation does not support %llu, so values will be wrong
		//after an extended period
		uint32_t delta = g_state.consumption - consumptionOld;
		uint32_t cons = g_state.consumption;
		DbgPrintf_P(PSTR("Consume: %luµAs (+%luµA)\r\n"), cons, delta);
	}
}

static void update_ldr(void) {
	uint8_t workmode;
	uint16_t v2 = 0;
	uint16_t v1 = 0;
	uint16_t v0 = 0;
	uint16_t v;
	uint8_t i;
	//start with 1MOhm
	adca_startup();
	PORTQ.PIN2CTRL = PORT_OPC_TOTEM_gc; //1MOhm
	PORTE.PIN4CTRL = PORT_OPC_TOTEM_gc; //1KOhm
	PORTE.PIN7CTRL = PORT_OPC_TOTEM_gc; //~50KOhm
	PORTA.PIN1CTRL = PORT_OPC_TOTEM_gc | PORT_ISC_INPUT_DISABLE_gc; //the ADC pin
	PORTQ.DIRSET = 4;
	PORTQ.OUTSET = 4;
	_delay_ms(2.0);
	uint16_t results[8];
	adca_getQuad(1, 1, 1, 1, ADC_REFSEL_VCC_gc, &(results[0]));
	adca_getQuad(1, 1, 1, 1, ADC_REFSEL_VCC_gc, &(results[4]));
	for (i = 0; i < 8; i++) {
		v2 += results[i];
	}
	PORTQ.DIRCLR = 4;
	PORTQ.OUTCLR = 4;
	PORTE.DIRSET = 0x80;
	PORTE.OUTSET = 0x80;
	for (i = 0; i < 8; i++) {
		v1 += adca_get(1);
	}
	PORTE.DIRCLR = 0x80;
	PORTE.OUTCLR = 0x80;
	PORTE.DIRSET = 0x10;
	PORTE.OUTSET = 0x10;
	for (i = 0; i < 8; i++) {
		v0 += adca_get(1);
	}
	adca_stop();
	PORTQ.PIN2CTRL = PORT_OPC_PULLDOWN_gc;
	PORTE.PIN4CTRL = PORT_OPC_PULLDOWN_gc;
	PORTE.PIN7CTRL = PORT_OPC_PULLDOWN_gc;
	PORTE.DIRCLR = 0x90;
	PORTE.OUTCLR = 0x90;
	PORTQ.DIRCLR = 4;
	PORTQ.OUTCLR = 4;
	v0 /= 8;
	v1 /= 8;
	v2 /= 8;
	if (v0 < 4000) {
		workmode = 0;
		v = v0;
	} else if (v1 < 4000) {
		workmode = 1;
		v = v1;
	} else {
		workmode = 2;
		v = v2;
	}
	g_state.ldr = (workmode << 14) | v;
/*
	DbgPrintf_P(PSTR("0x%x\r\n"), g_ldr);
*/
}

static void update_temperature(void) {
	uint16_t v = 0;
	uint8_t i;
	adcb_startup();
	PORTQ.PIN2CTRL = PORT_OPC_TOTEM_gc;
	PORTB.PIN0CTRL = PORT_OPC_TOTEM_gc | PORT_ISC_INPUT_DISABLE_gc; //the ADC pin
	PORTQ.OUTSET = 4;
	PORTQ.DIRSET = 4;
	_delay_ms(0.05); //reaches 80% of the voltag after 20µs
	for (i = 0; i < 8; i++) {
		v += adcb_get(0);
	}
	adcb_stop();

	PORTQ.DIRCLR = 4;
	PORTQ.OUTCLR = 4;
	PORTQ.PIN2CTRL = PORT_OPC_PULLDOWN_gc;
	/* 1. step, calculate resistance of sensor.
		Rx = R1/((1.6*4095*8)/v -1);
		Rx = 4700/(52416/v -1);
		Rx = (4700*v)/(52416 -v)
*/
	//uint32_t ohm = ((uint32_t)v*4700)/(3069-v);
	uint32_t ohm = ((uint32_t)v*4700)/(52416-v);
	/* 3. grade polynomia with 0, 25, 50 and 80°C:
		2.12x10^-9*ohm^3 -0.0000224786*ohm^2 + 0.128189*ohm - 157.224
		3. grade not representable in 32bit.

		2. grade polynomia: with 0, 50 and 100°C
 -0.0000070424599426781825*x^2 +0.09231465863293291*x-130.5806904123189

		Calculate with 1/10 grad and then round proper

	int16_t gradcelsius = (-(ohm*ohm*10/141996) + (ohm*100/108) - 1306);

	Error calculation:
	AD value sum 8xsampled: 15734, R1 +-1% 4700Ohm:
	RxMin = 1994Ohm @ R1=4653  -> temperature: 25,49°C
	RxBest = 2015Ohm @ R1=4700 -> temperature: 26,8°C
	RxMax = 2035Ohm @ R1=4747  -> temperature: 28,11°C
	Rounding error by ohm*100/108: +0.56°C
	Rounding error by polynomia: -0.002°C
-69: Calibration offset
	*/
	g_state.gradcelsius10 = (-(ohm*ohm*10/141996) + (ohm*200/217) - 1306 - 182);
}

/*
To not get confused with all the various light and bright values:
g_state.ldr -> sampled A/D value from photoresistor
g_state.brightnessLdr -> calculated from g_state.ldr, would be used if auto adjust
g_settings.brightness -> would be used under manual control
g_state.brigthness -> current brightness for display to use
*/
static void update_display_brightnessMeasure(void) {
	if ((g_settings.brightnessAuto) || (g_dispUpdate == updateLightText) ||
	    (g_dispUpdate == updateDispbrightText)) {
		update_ldr();
	}
	uint8_t newbrightness = 0;
	if ((g_settings.brightnessAuto) || (g_dispUpdate == updateDispbrightText)) {
		if ((g_settings.brightnessNoOff) || (g_state.displayNoOffCd)) {
			newbrightness = 1;
		}
		if (g_state.ldr < 0x8CE4) { //mode 2 + 3300
			newbrightness = 4;
		}
		if (g_state.ldr < 0x8C62) { //mode 2 + 3250
			newbrightness = 10;
		}
		if (g_state.ldr < 0x8BB8) { //mode 2 + 3000
			newbrightness = 20;
		}
		if (g_state.ldr < 0x87D0) { //mode 2 + 2000
			newbrightness = 40;
		}
		if (g_state.ldr < 0x8190) { //mode 2 + 400
			newbrightness = 90;
		}
		if (g_state.ldr < 0x47D0) { //mode 1 + 2000
			newbrightness = 128;
		}
		if (g_state.ldr < 0x4460) { //mode 1 + 1200
			newbrightness = 196;
		}
		if (g_state.ldr < 0x4000) { //mode 0 + 0
			newbrightness = 255;
		}
		g_state.brightnessLdr = newbrightness;
	}
}

static void update_display_brightnessAdjust(void) {
	uint8_t newbrightness;
	//1. determine target brigtness
	if ((g_state.powersaveEnabled) && (g_state.displayNoOffCd == 0)) {
		newbrightness = 0; //power save
	} else if (g_settings.brightnessAuto) {
		//newbrightness = value if the LDR would be used
		newbrightness = g_state.brightnessLdr;
	} else {
		//user selectedbrightness
		newbrightness = g_settings.brightness;
	}
	//newbrightness = value according to LDR changes or user select
	//2. count down adjustment blocking
	if (g_state.brightDownCd) g_state.brightDownCd--;
	if (g_state.brightUpCd) g_state.brightUpCd--;
	//3. fast adjust within few seconds target brightness should be reached
	int16_t brightdelta = newbrightness - g_state.brightness;
	newbrightness = g_state.brightness; //default case, keep as current
	if (brightdelta < 0) {
		g_state.brightUpCd = 8; //when ramping down, prevent ramping up soon
		if ((g_state.brightDownCd == 0) || (brightdelta < -20)) {
			int16_t adjust = brightdelta/4;
			if (adjust == 0) {
				adjust = -1;
			}
			newbrightness += adjust;
		}
	} else if (brightdelta > 0) {
		g_state.brightDownCd = 8; //when ramping up, prevent ramping down soon
		if ((g_state.brightUpCd == 0) || (brightdelta > 20)) {
			int16_t adjust = brightdelta/4;
			if (adjust == 0) {
				adjust = 1;
			}
			newbrightness += adjust;
		}
	} else {
		g_state.brightUpCd = 6;
		g_state.brightDownCd = 6;
	}
	//4. update brightness if value differs
	if (newbrightness != g_state.brightness) {
		disp_configure_set(newbrightness, g_settings.displayRefresh);
		g_state.brightness = newbrightness;
	}
	//debug output:
	if (g_settings.debugRs232 == 3) {
		DbgPrintf_P(PSTR("BrVals: %u %i %i %i %i %i\r\n"),
		g_state.ldr, g_state.brightnessLdr, g_settings.brightness,
  	brightdelta, newbrightness, g_settings.brightnessAuto);
		if ((g_state.powersaveEnabled) && (g_state.displayNoOffCd)) {
			DbgPrintf_P(PSTR("Powersave in %is\r\n"), g_state.displayNoOffCd);
		}
	}
}


static void watchdog_enable(void) {
	CCP = 0xD8; //change protection
	//WDT_CTRL = (9 << 2) | 3; //enable with 4seconds timeout
	WDT_CTRL = (0xA << 2) | 3; //enable with 8seconds timeout
}

#define IRKEYS 4
#define VERIFYCHECKS 20

//filters high noise, like flickering LED lightning
#define IRMAX 2800

/*Note: Energy could be conserved by not fully rise the voltage
  when using SLOW_RISING. However then it must be taken care of the fact that
  the first channel will have a constantly lower sampled value as the voltage
  would rise for all channels while sampling is in progress.
  A more deterministic AD value could be aquired by using the event system and
  a timer when applying power. Currently the _delay_us is sometimes increased
  by interrupts which affects AD values by the longer rise time.
*/
static void irKeyPowerup(void) {
#ifdef SLOW_RISING
	PORTA.PIN2CTRL = PORT_OPC_PULLDOWN_gc;
	_delay_us(150.0); //50us is not enough for slowly rising power
#else
	PORTA.PIN2CTRL = PORT_OPC_TOTEM_gc;
	PORTA.DIRSET = 0x04;
	PORTA.OUTCLR = 0x04; //the output is low active, enable IR LEDs
	_delay_us(80.0);
#endif
}

static void irKeyPowerdown(void) {
#ifdef SLOW_RISING
	PORTA.PIN2CTRL = PORT_OPC_PULLUP_gc;
#else
	PORTA.OUTSET = 0x04; //disable IR LEDs
#endif
}

static uint8_t irKeysRead(void) {
#if 0
	uint16_t val[IRKEYS];
	uint16_t valVerify[VERIFYCHECKS];
	uint8_t key = 0;
	uint8_t numkeys = 0;
	uint16_t avg = 0;
	irKeyPowerup();
	adca_startup();
	adca_getQuad(3, 4, 5, 6, ADC_REFSEL_VCC_gc, val);
	irKeyPowerdown();
	for (uint8_t i = 0; i < IRKEYS; i++) {
		avg += val[i];
	}
	avg = (avg >> 2) * 9/10; //90% limit of average value (>>2 represents IRKEYS)
	for (uint8_t i = 0; i < IRKEYS; i++) {
		if ((val[i] < avg) && (val[i] < (IRMAX))) {
			//verify to filter out noise
			irKeyPowerup();
			adca_getQuad(i+3, i+3, i+3, i+3, ADC_REFSEL_VCC_gc, valVerify);
			irKeyPowerdown();
			uint8_t j;
			uint8_t verified = 0;
			for (j = 0; j < VERIFYCHECKS; j++) {
				if (valVerify[j] < avg) {
					verified++;
				}
			}
			if (verified == VERIFYCHECKS) {
				key = i + 1;
				numkeys++;
			}
		}
	}
	adca_stop();
#else
	/*The signal of the pressed key must be present in every measurement
		until all values have stabilized
	*/
	uint16_t val[IRKEYS];
	uint8_t key;
	uint8_t keyLast = 0;
	uint16_t avgLast = 0x0;
	uint8_t numkeys = 0;
	uint8_t j;
	irKeyPowerup();
	adca_startup();
	for (j = 0; j < VERIFYCHECKS; j++) {
		adca_getQuad(3, 4, 5, 6, ADC_REFSEL_VCC_gc, val);
		uint16_t avg = 0;
		for (uint8_t i = 0; i < IRKEYS; i++) {
			avg += val[i];
		}
		avg = (avg >> 2) * 8/10; //80% limit of average value (>>2 represents IRKEYS)
		key = 0;
		for (uint8_t i = 0; i < IRKEYS; i++) {
			if ((val[i] < avg) && (val[i] < (IRMAX))) {
				key = i + 1;
				numkeys = 1;
			}
		}
		if (key == 0) {
			break; //early out because no key signal on first try
		}
		if ((keyLast) && (keyLast != key)) { //not the same key as previous round
			numkeys = 2;
			break;
		}
		if (avg <= avgLast) {
			break; //no decrease in power anylonger
		}
		avgLast = avg;
		keyLast = key;
	}
	irKeyPowerdown();
	adca_stop();
#endif
	g_state.keyDebugAd = val[1];
	if (g_settings.debugRs232 == 4) {
		DbgPrintf_P(PSTR("IR (%u) %u %u %u %u\r\n"), j, val[0], val[1], val[2], val[3]);
	}
	if (numkeys == 1) {
		if ((g_settings.debugRs232) && (key)) {
			DbgPrintf_P(PSTR("Pressed %c\r\n"), 'A'+key-1);
		}
		return key;
	}
	return 0;
}

static void update_alarmAndSound(void) {
	if (g_state.timerCountdownSecs) {
		g_state.timerCountdownSecs--;
		if (!g_state.timerCountdownSecs) {
			g_state.soundEnabledCd = g_settings.soundAutoOffMinutes*60;
			g_state.soundDisableState = 3;
		}
	}
	if (g_state.soundEnabledCd) {
		g_state.soundEnabledCd--;
		if (!(g_state.soundEnabledCd)) {
			g_state.soundDisableState = 0;
		}
		//half second beep, half second off, etc
		sound_beep(g_settings.soundVolume, g_settings.soundFrequency, 500);
	}
}

static uint8_t rc5keyget(void) {
	uint16_t rc5data = rc5getdata();
	if (rc5data) {
		if (g_settings.debugRs232 == 0xD) {
			DbgPrintf_P(PSTR("RC-5: 0x%x\r\n"), rc5data);
		}
		rc5data &= ~0x800; //mask out toggle bit
		if ((g_state.rc5entermode) && (g_state.rc5entermode <= RC5KEYS)) {
			g_settings.rc5codes[g_state.rc5entermode-1] = rc5data;
		} else {
			uint8_t i;
			for (i = 0; i < RC5KEYS; i++) {
				if (g_settings.rc5codes[i] == rc5data) {
					return i+1;
				}
			}
		}
	}
	return 0;
}

static void update_rc5control(void) {
	uint8_t modeshould = 0;
	if (g_state.rc5Cd) {
		g_state.rc5Cd--;
	}
	if (((g_state.rc5Cd) && (g_settings.rc5mode > 0)) ||
	   (g_settings.rc5mode == 3)) {
		modeshould = 1;
	}
	if (modeshould != g_state.rc5modeis) {
		if (modeshould) {
			rc5Init();
			if (g_settings.debugRs232 == 0xD) {
				rs232_sendstring_P(PSTR("RC-5 receiver enabled\r\n"));
			}
		} else {
			rc5Stop();
			if (g_settings.debugRs232 == 0xD) {
				rs232_sendstring_P(PSTR("RC-5 receiver disabled\r\n"));
			}
		}
		g_state.rc5modeis = modeshould;
	}
}

static void rc5keypress(void) {
	if (g_settings.rc5mode == 1) {
		g_state.rc5Cd = 60; //60seconds on
	} else if (g_settings.rc5mode == 2) {
		g_state.rc5Cd = 60*5; //5min on
	}
}

static void update_rfm12control(void) {
	DEBUG_FUNC_ENTER(update_rfm12control);
	uint8_t modeshould = 0;
	if (g_state.rfm12Cd) {
		g_state.rfm12Cd--;
	}
	if (((g_state.rfm12Cd) && (g_settings.rfm12mode > 0)) ||
	   (g_settings.rfm12mode == 3)) {
		modeshould = 1;
	}
	if (modeshould != g_state.rfm12modeis) {
		if (modeshould) {
			rs232_sendstring_P(PSTR("RFM12 enabling...\r\n"));
			rfm12_init();
		} else {
			rs232_sendstring_P(PSTR("RFM12 enter standby...\r\n"));
			rfm12_standby();
		}
		g_state.rfm12modeis = modeshould;
		//some brightness values result in a non working RFM12 - need to avoid
		disp_configure_set(g_state.brightness, g_settings.displayRefresh);
	}
	DEBUG_FUNC_LEAVE(update_rfm12control);
}

static void rfm12keypress(void) {
	if (g_settings.rfm12mode == 1) {
		g_state.rfm12Cd = 60; //60seconds on
	} else if (g_settings.rfm12mode == 2) {
		g_state.rfm12Cd = 60*5; //5min on
	}
}

static void increaseRfmTimeout(void) {
	/*When sending the log data, this might take some time, so do not
	  switch off the rfm12 while sending.
	  64k/23Byte -> 2850messages to send -> 3 per second -> up to 15min for all
	  messages. The observed transmission rate is 4 per second. So enough reserve.
	  This still might be too little in the case of a very high retransmission
	  rate due to bad connection. But in this case... make connection better or
	  set rfm12 to permanently on, or press some buttons to increase timeout.
	*/
	if ((g_state.rfm12modeis) && (g_state.rfm12Cd < 60*15)) {
		g_state.rfm12Cd = 60*15;
	}
}
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
int main(void) {
	pull_all_pins();
	watchdog_enable();
	power_setup();
	stackCheckInit(); //must be called before enabling ints
	disp_rtc_setup();
	g_settings.debugRs232 = 1; //gets overwritten by config_load() anyway
	rs232_sendstring_P(PSTR("Advanced-Clock V0.9.3\r\n"));
	g_state.printPing = 1;
	config_load();
	g_state.batteryCharged = g_settings.batteryCapacity;
	g_state.batteryCharged *= (60*60); //mAh -> mAs
	sei();
	uint8_t resetsource = reset_print();
	resetcounter_increase();
	gui_init();
	charger_calib(); //takes a long time
	logger_init(); //can take some time
	loggerlog_bootup(g_settings.reboots, resetsource, g_debug, g_debugint);
	g_debug = 0;
	calibrate_start();
	g_state.irKeyUse = input_detect();
	if (g_settings.debugRs232 >= 2) {
		rs232_rx_init();
	}
	disp_configure_set(g_settings.brightness, g_settings.displayRefresh);
	g_state.brightness = g_settings.brightness;
	rfm12_standby();
	performance_counter_init();
	g_state.subsecond = rtc_8thcounter;
	while(1) {
		uint8_t rtc_8thcounter_l = rtc_8thcounter; //rtc_8thcounter updated by interrupt
		if (rtc_8thcounter_l != g_state.subsecond) { //1/8th second passed
			uint8_t delayed = 0;
			uint8_t subsecnext = g_state.subsecond + 1;
			if (subsecnext !=  rtc_8thcounter_l) {
				delayed = 1; //something took too much time
				if (g_settings.debugRs232 == 0xE) {
					rs232_sendstring_P(PSTR("TimeE\r\n"));
				}
			}
			run8xS(delayed);
			if ((g_state.subsecond & 1) == 0) {
				run4xS();
			}
			if ((g_state.subsecond & 3) == 0) {
				run2xS();
			}
			if ((g_state.subsecond & 7) == 0) {
				run1xS();
			}
			/*g_state.subsecond should be now equal to rtc_8thcounter, if not we
			  will try to catch up and do not skip updates. Only after 32sec behind,
			  we skip.
			  Needing to catch up more than one second might result in missing the
			  alarm!
			*/
			g_state.subsecond++;
		} else {
			if (((g_settings.flickerWorkaround == 0) || (g_state.brightness == 0)) &&
			   ((PR_PRPD & PR_PRPE & PR_PRPF) == 0x7F) &&
			   ((PR_PRPA & PR_PRPB) == 0x7) &&
			   ((PR_PRPC & 0x7D) == 0x7D) && //TC1 may be active for performance measurement
			   (PR_PRGEN == 0x1B)) {
				//if no periphery is running except the rtc, stop the cpu
				SLEEP.CTRL = (3<<1) | 1; //power save
			} else {
				//00 7F 6F 7F 07 07 1B
				if (g_settings.debugRs232 == 9) {
					rs232_puthex(PR_PRPC);
					rs232_puthex(PR_PRPD);
					rs232_puthex(PR_PRPE);
					rs232_puthex(PR_PRPF);
					rs232_puthex(PR_PRPA);
					rs232_puthex(PR_PRPB);
					rs232_puthex(PR_PRGEN);
					rs232_putchar('\r');
					rs232_putchar('\n');
				}
				SLEEP.CTRL = 1; //idle
			}
			rtc_waitsafeoff();
			uint16_t cntBeforeOff = TCC1.CNT;
			g_state.performanceUp = 0;
			sleep_cpu();
			uint16_t cntAfterOff = TCC1.CNT;
			SLEEP.CTRL = 0;
			if (g_state.performanceUp) {
				g_state.performanceOff += g_state.performanceUp - cntBeforeOff;
			} else {
				//counters never overflow here, so its safe
				g_state.performanceOff += cntAfterOff - cntBeforeOff;
			}
		}
	}
}

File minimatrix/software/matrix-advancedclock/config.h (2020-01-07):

#ifndef CONFIG_H
#define CONFIG_H

#include <stdint.h>

#define CURRENTRESCAL_NORMAL 220
#define CURRENTRESCAL_MIN 180
#define CURRENTRESCAL_MAX 240

#define CONSUMPTIONLEDONEMAX_NORMAL 400
#define CONSUMPTIONLEDONEMAX_MIN 100
#define CONSUMPTIONLEDONEMAX_MAX 1000

//mAh the user can set as maximum
#define BATTERYCAPACITY_MAX 3000
//an old 760mAh battery might just have 200mAh left after some years
#define BATTERYCAPACITY_MIN 150

#define DCF77LEVEL_NORMAL 60
#define DCF77LEVEL_MAX 150
#define DCF77LEVEL_MIN 2

//milliseconds/day the crystal goes wrong
#define TIMECALIB_MAX 30000
#define TIMECALIB_MIN (-TIMECALIB_MAX)

#define ALARMS 2
#define RC5KEYS 4

#define RFM12_KEYQUEUESIZE 4

/*
Every data which should be stored in the EEPROM must be defined in settings_t.
An additional CRC of the structure is stored there too.
Every data which are state variabels (used for more than one iteration and
therefore are not local variables of data given as function call arguments)
and are used by more than one .c file should be stored in sysstate_t.
So by default no variables needs to be defined as external somewhere (there are
some exceptions).
*/

typedef struct {
	/* Level of debug:
		0: no rs232 out
		1: basic messages
		2: as 1 + control input
		3. as 2 + brightness adjustment print
		4. as 2 + IR key print or touch print
		5. as 2 + DCF77 print (full minute sample)
		6. as 2 + RFM12 print
		7. as 2 + charger print
		8. as 2 + adc calibration values
		9. as 2 + reasons for not stopping rc oscillator
		A. as 2 + estimated consumption
		B. as 2 + DCF77 print (timer adjust + unconverted time received)
		C. as 2 + Logger messages
		D. as 2 + RC5 messages
		E. as 2 + timing exceeds
		F. as 2 + memory statistics
	*/
	uint8_t debugRs232;
	uint8_t alarmEnabled[ALARMS];  //0: Disabled, 1: Enabled
	uint8_t alarmHour[ALARMS];     //0...23 [hours]
	uint8_t alarmMinute[ALARMS];   //0...59 [minutes]
	uint8_t alarmWeekdays[ALARMS];  //each bit one day of the week. lsb = monday
	uint16_t timerMinutes; //[minutes]
	uint8_t brightnessAuto; //0: Manual brightness control, 1: Automatic brightness control
	uint8_t brightness;     //brighntess for manual brightness
	uint8_t brightnessNoOff; //if 1, never go to brightness 0.
	uint8_t clockShowSeconds; //[seconds]
	uint8_t soundAutoOffMinutes; //[minutes]
	uint8_t soundVolume;     //0: min, 255: max
	uint16_t soundFrequency; //[Hz]
	uint16_t displayRefresh; //[Hz]
	uint8_t chargerMode; //0: auto, 1: off, 2: on (on gets converted to auto on startup)
	uint16_t consumptionLedOneMax; //consuption in [µA] of one dot lighting 1/5 (5 lines) of the time
	uint16_t batteryCapacity; //[mAh]
	uint16_t currentResCal; //[10*mOhm] Calibrated value of the resistor (R46) for measuring the input current in 1/100 th of Ohm
	uint16_t dcf77Level; //number of errors one sampled minute (38bit) might have
	uint8_t rc5mode;     //0: off, 1: on for 5min if user entered something or beeper is enabled. 2: always on
	uint16_t rc5codes[RC5KEYS]; //infrared code for key left, 0 = none, [0] = left, [1] = down, [2] = up, [3] = right
	uint8_t rfm12mode;   //0: off, 1: on for 1min if user entered something or beeper is enabled. 2: 5min if user entered something or beeper is enabled, 3: always on
	uint32_t reboots;    //number of power ups
	uint32_t usageseconds; //number of seconds this device has run [seconds]
	uint8_t powersaveHourStart; //standby starts when the time is equal to this value and the weekday fits [hours]
	uint8_t powersaveMinuteStart; //standby starts when the time is equal to this value and the weekday fits [minutes]
	uint8_t powersaveHourStop; //standby stops when the time is equal to this value [hours]
	uint8_t powersaveMinuteStop;//standby stops when the time is equal to this value [minutes]
	uint8_t powersaveWeekdays;  //each bit one day of the week. lsb = monday
	//new settings start here
	uint16_t rfm12passcode; //initial number which must be entered in order to accept commands. 0...999
	uint8_t summertimeadjust; //0 = no summer time adjust, 1 = summer time adjust
	uint8_t loggerPeriod; //[hours] until resync of dcf after last sync stopped
	uint8_t dcf77Period; //[hours] how often a log is written
	uint8_t flickerWorkaround; //if 1, workaround for display flicker is enabled (at the cost of more power consumption)
	int16_t timeCalib; //[ms] the clock should go faster or slower each day
	uint8_t powersaveBatteryBelow; //[%] only enable powersave if battery is below this threshold
	uint8_t reserved[28]; //decrease if new settings get in, so no crc mismatch on next start
} settings_t;

typedef struct {
	uint8_t ksize;
	uint16_t maxentries; //the maximum elements in the ring buffer
	uint16_t nextentry; //the index in the ring buffer
	uint32_t nextid; //the always incrementing ID for each log entry
	uint8_t reportingmode; //0 = none, 1 = hex, 2 = human readable
	uint16_t reportingindex; //we cant report everything in one cycle
} loggerstate_t;
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

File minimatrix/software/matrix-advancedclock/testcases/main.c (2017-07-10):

#include <stdlib.h>
#include <stdint.h>
#include <stdio.h>

#include "../config.h"

#include "testcharger.h"
#include "testdcf77decoder.h"
#include "testtimeconvert.h"
#include "testrfm12.h"
#include "testfinecalib.h"

settings_t g_settings;
sysstate_t g_state;

int g_lastaction;

void menu_keypress(uint16_t key) {
	g_lastaction = key;
}

int main(void) {
	int errors = 0;
	errors += testcharger();
	errors += testdcf77decoder();
	errors += testtimeconvert();
	errors += testrfm12();
	errors += testfinecalib();
	if (errors) {
		printf("Errors: %i\n", errors);
		return 1;
	}
	printf("No errors :)\n");
	return 0;
}

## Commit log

2016-08-14 Adding schematics and pcbs
    [ir-sensorboard.brd, ir-sensorboard.sch, minimatrixV1-1.brd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]
2016-09-04 Simpleclock: Bugfix Display did not light up after user keypress in dark environment.
    [main.c]
2016-09-25 Add advanced version - RFM12 not working
    [adc.c, charger.c, config.h]
2016-10-09 Add protection circuit
    [solarvoltagelimit.sch]
2016-11-16 Abort DCF sync if sync failed for two hours. Retry one hour later with new calibrated oscillator. Disable keys between 2h and 4h, if sync failed for at least one hour, to reduce noise. Change screen 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
    [config.h, dcf77.c, gui.c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]
2017-01-02 Add pintest description. Bugfix: Logger did not work with 64kB eeproms. Bugfix: Logger used only one entry after initial power-up with new eeprom
    [logger.c]
2017-01-19 Add RX support for RFM12. No act of packages yet. Reduce CPU load by optimizing redrawing and caching time. Fix bug where last pressed key could not disable beeping alarm. Add menu points for setting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
    [config.h, gui.c, logger.c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]
2017-02-05 RFM12 support mostly complete including test cases. Still gets some unusal high CRC error rates. Had to decrease the data rate from 20000 to 10000 baud in order to get less problems with data loss du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
    [logger.c, main.c, rfm12.c]
2017-02-13 Complete RFM12 rx/tx. In the case of critical CPU load, printing log is delayed Printing log only continues if there is enough free space in the RFM12 tx buffer Fix rs232_puthex Debug mode 0xE report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
    [config.h, logger.c, main.c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]
2017-03-06 Fix plopping sound at end of a beep. Increase maximum beeper volume. Add options to adjust period for logger and dcf77 sync Add option to adjust to daylight saving time Add workaround for display fli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
    [config.h, dcf77.c, gui.c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]
2017-04-01 Fix date from timestamp calculation for dates after 2038. Support manual setting of time and date. Support manual adjusting of charged state. Add workaround for random display flicker at the cost of 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
    [charger.c, config.h, dcf77.c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]
2017-04-02 Fix logger printing endlessly and starting with wrong entry when log memory is completely filled. Support manual ajusting of charged state.
    [charger.c, config.h, gui.c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]
2017-06-11 Completing hardware documentation including partlist
    [minimatrixV1-1.brd, minimatrixV1-1.sch, minimatrixV1-2.brd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]
2017-06-11 Add missing file, add new image, update notes within voltage limiter schematic
    [solarvoltagelimit.brd, solarvoltagelimit.sch]
2017-07-10 Add screen for testing pattern. Add clock calibration option and testcases therefore. Option for enabling/disabling ping print. Resyncs with a big time difference need to have a lower error than usua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
    [config.h, dcf77.c, gui.c]
2017-07-20 Fix finecalibration. Fix UART (no bad character if CPU clock is boosted, use pullup instead of pulldown). Fix IR key input. Fix compiler warning in RFM12 testcase. Add heap->stack range check (shows 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
    [config.h, dcf77.c]
2017-09-03 Version 0.8 Merge doubled code from advanced and simple clock software. Fix some bugs in simple version which were already fixed in advanced version. Clean up debug messages - makes code more easy to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
    [adc.c, charger.c, dcf77.c]
2018-06-10 Version 0.9.1 Add powersave depending on battery state Add printout of eeprom config Reduce possibility of false inputs from IR keys Reduce flicker in simlple clock version Optimize plotting scripts 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
    [config.h, gui.c, logger.c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]
2018-06-14 Fix RFM12 buffer overflow - data are thrown away if they can not be send in time. Add timeout to the keylock.
    [config.h, gui.c, main.c]
2020-01-07 Bugfix: Do not disable ringing alarm during other input by accident. Do not do input while disabling alarm by accident. Bugfix: Have auto disable alarm, working properly if timeout is greater than 4m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
    [config.h, main.c, rfm12.c]

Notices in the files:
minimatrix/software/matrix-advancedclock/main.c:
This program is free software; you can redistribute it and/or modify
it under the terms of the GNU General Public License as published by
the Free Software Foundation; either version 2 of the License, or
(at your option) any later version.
